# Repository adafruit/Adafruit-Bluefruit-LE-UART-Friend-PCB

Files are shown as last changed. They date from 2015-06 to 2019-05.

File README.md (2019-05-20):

# Adafruit Bluefruit LE UART Friend PCB
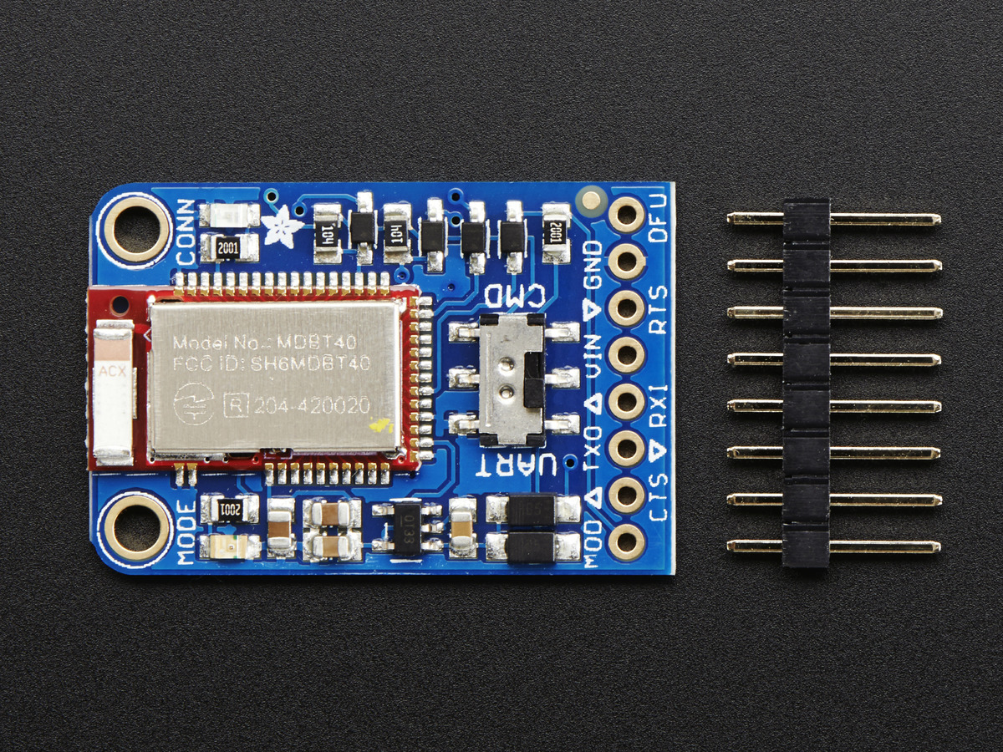
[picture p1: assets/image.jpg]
<a href="http://www.adafruit.com/products/2479"><br/>
Click here to purchase one from the Adafruit shop</a>

The Bluefruit LE UART Friend makes it easy to add Bluetooth Low Energy connectivity to anything with a hardware or software serial port. We even have nice hardware flow control so you won't have to think about losing data. Connect to your Arduino or other microcontroller or even just a standard FTDI cable for debugging and testing.

This multi-function module can do quite a lot! For most people, they'll be very happy to use the standard Nordic UART RX/TX connection profile. In this profile, the Bluefruit acts as a data pipe, that can 'transparently' transmit back and forth from your iOS or Android device. You can use our iOS App or Android App, or write your own to communicate with the UART service.

PCB files for Adafruit Bluefruit LE UART Friend. Format is EagleCAD. 
- https://www.adafruit.com/product/2479

### License

Adafruit invests time and resources providing this open source design, please support Adafruit and open-source hardware by purchasing products from [Adafruit](https://www.adafruit.com)!

All text above must be included in any redistribution

Designed by Limor Fried/Ladyada for Adafruit Industries.
Creative Commons Attribution/Share-Alike, all text above must be included in any redistribution. 
See license.txt for additional information.

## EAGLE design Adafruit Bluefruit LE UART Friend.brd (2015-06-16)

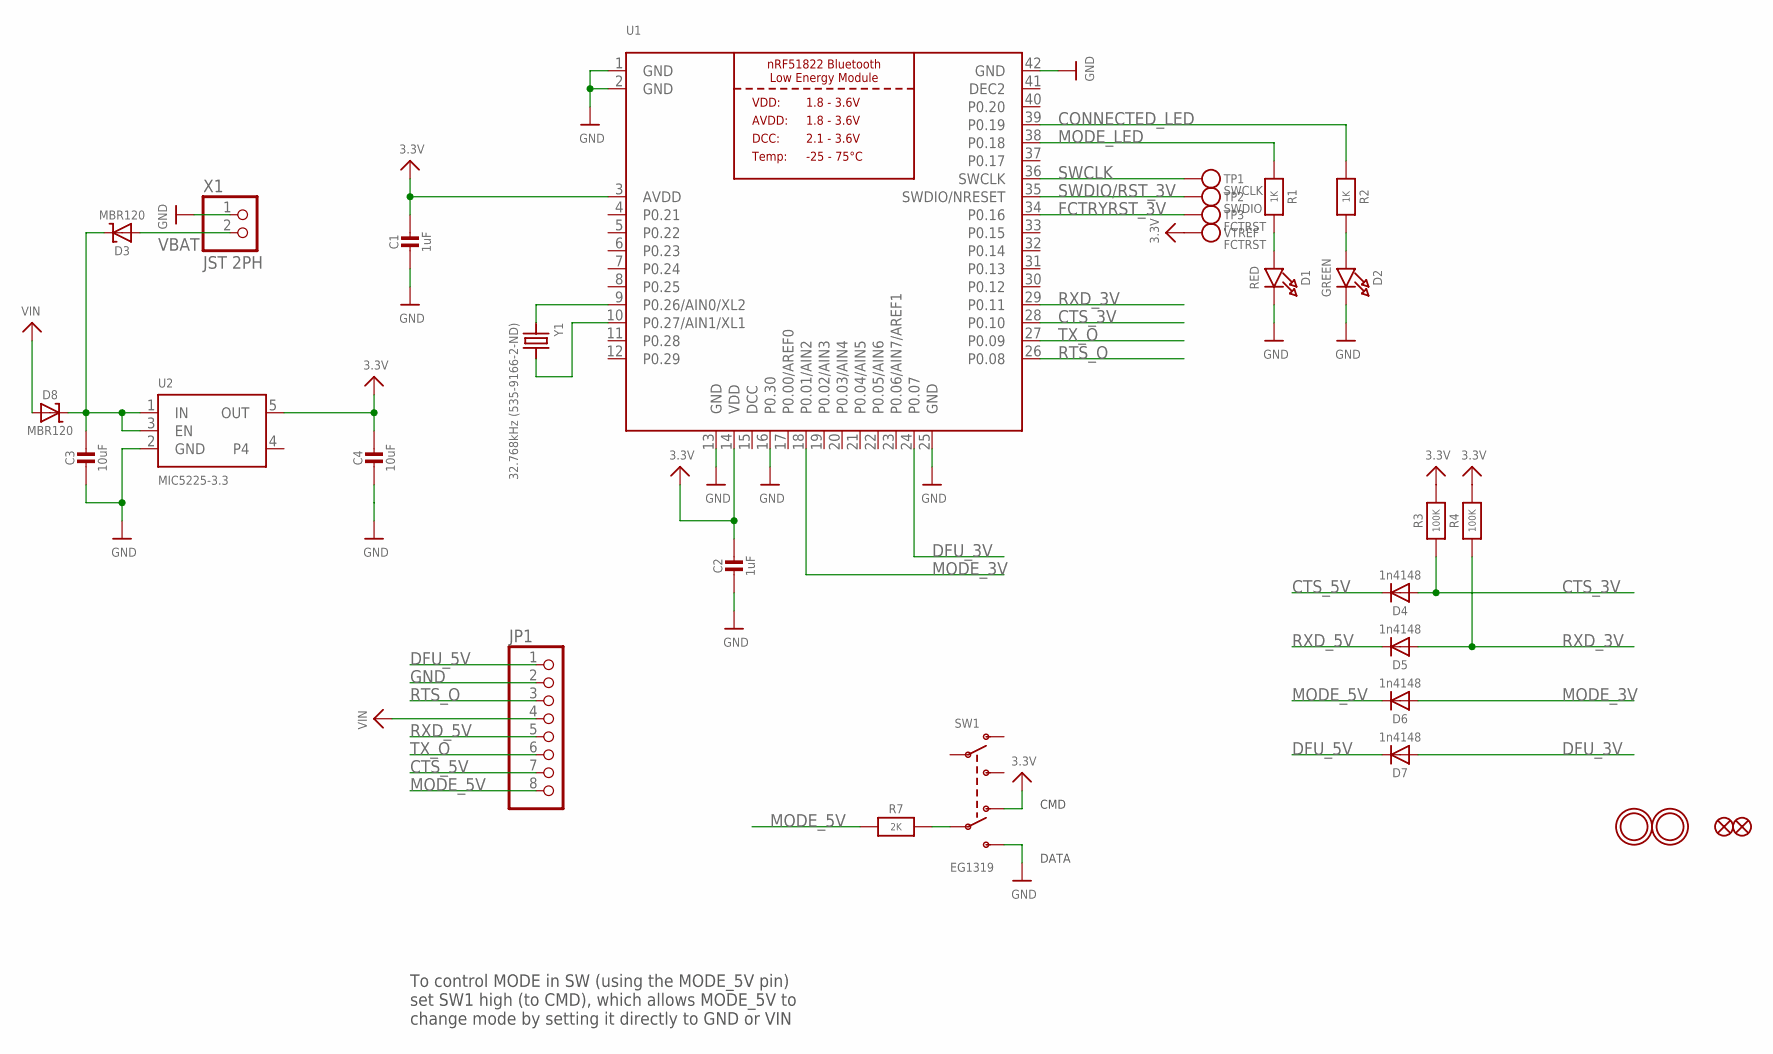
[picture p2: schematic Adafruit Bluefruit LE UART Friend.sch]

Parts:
C1, C2: 1uF; 0805-NO
C3, C4: 10uF; 0805-NO
D1: RED; CHIPLED_0805_NOOUTLINE
D2: GREEN; CHIPLED_0805_NOOUTLINE
D3, D8: MBR120; SOD-123
D4, D5, D6, D7: 1n4148; SOD-323
FID1, FID2: FIDUCIAL""; FIDUCIAL_1MM
JP1: HEADER-1X876MIL; 1X08_ROUND_76
R1, R2: 1K; 0805-NO
R3, R4: 100K; 0805-NO
R7: 2K; 0805-NO
SW1: EG1319; EG1390
TP1: SWCLK; PAD-1.5X2.0
TP2: SWDIO; PAD-1.5X2.0
TP3: FCTRST; PAD-1.5X2.0
U1: NRF51822_MODULE_MDBT40; BLE_MODULE_RAYTAC_MDBT40
U2: MIC5225-3.3; SOT23-5
U$28, U$29: MOUNTINGHOLE2.5; MOUNTINGHOLE_2.5_PLATED
VTREF: FCTRST; PAD-1.5X2.0
X1: JST 2PH; JSTPH2
Y1: 32.768kHz (535-9166-2-ND); CRYSTAL_CYL_2X6MM_SMT

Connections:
3.3V: C1.1, C2.1, C4.1, R3.2, R4.2, SW1.O2, U1.3 (AVDD), U1.14 (VDD), U2.5 (OUT), VTREF.P$1
CONNECTED_LED: R2.1, U1.39 (P0.19)
CTS_3V: D4.A, R3.1, U1.28 (P0.10)
CTS_5V: D4.C, JP1.7
DCC: U1.15 (DCC)
DEC2: U1.41 (DEC2)
DFU_3V: D7.A, U1.24 (P0.07)
DFU_5V: D7.C, JP1.1
FCTRYRST_3V: TP3.P$1, U1.34 (P0.16)
GND: C1.2, C2.2, C3.2, C4.2, D1.C, D2.C, JP1.2, SW1.S2, U1.1 (GND), U1.2 (GND), U1.13 (GND), U1.16 (P0.30), U1.25 (GND), U1.42 (GND), U2.2 (GND), X1.1
MODE_3V: D6.A, U1.18 (P0.01/AIN2)
MODE_5V: D6.C, JP1.8, R7.1
MODE_LED: R1.1, U1.38 (P0.18)
unnamed: U1.9 (P0.26/AIN0/XL2), Y1.1
unnamed: U1.10 (P0.27/AIN1/XL1), Y1.2
unnamed: C3.1, D3.C, D8.C, U2.1 (IN), U2.3 (EN)
unnamed: R7.2, SW1.P2
unnamed: D1.A, R1.2
unnamed: D2.A, R2.2
RTS_O: JP1.3, U1.26 (P0.08)
RXD_3V: D5.A, R4.1, U1.29 (P0.11)
RXD_5V: D5.C, JP1.5
SWCLK: TP1.P$1, U1.36 (SWCLK)
SWDIO/RST_3V: TP2.P$1, U1.35 (SWDIO/NRESET)
TX_O: JP1.6, U1.27 (P0.09)
VBAT: D3.A, X1.2
VIN: D8.A, JP1.4

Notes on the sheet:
DATA
CMD
To control MODE in SW (using the MODE_5V pin) set SW1 high (to CMD), which allows MODE_5V to change mode by setting it directly to GND or VIN

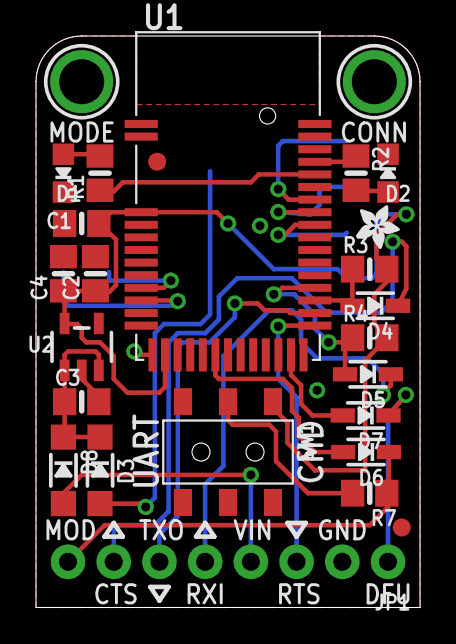
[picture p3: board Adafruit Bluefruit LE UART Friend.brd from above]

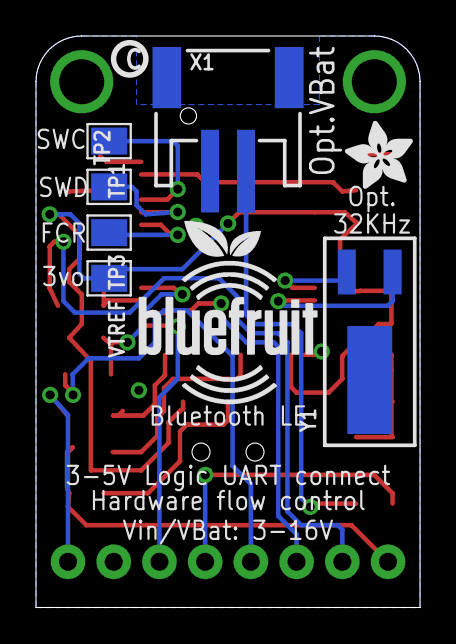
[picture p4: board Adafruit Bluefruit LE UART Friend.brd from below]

Board: 2 copper layers, 21.3 x 31.8 mm, 35 parts (9 on the bottom side), 25 nets.

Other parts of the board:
U$9: BLUEFRUITLOGO_100MM
U$24: PCBFEAT-REV-040
U$25: ADAFRUIT_3.5MM
U$26: ADAFRUIT_2.5MM

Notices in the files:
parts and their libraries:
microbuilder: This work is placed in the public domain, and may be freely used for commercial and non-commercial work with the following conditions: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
